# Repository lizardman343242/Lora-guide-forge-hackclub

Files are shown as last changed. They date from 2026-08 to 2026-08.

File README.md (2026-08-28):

# Lora-guide-forge-hackclub





This project follows the stranded guide from forge connecting the RP2040 to the Lora module leading into a antenna 

Bom Table
---
| Id | Designator | Footprint | Quantity | Designation | Supplier and ref |
|----|---|---|---|---|---|
| 1 | AE1 | PinSocket_1x01_P2.54mm_Vertical | 1 | Antenna | |
| 2 | C2, C3 | C_0402_1005Metric | 2 | 100nf | https://jlcpcb.com/partdetail/1877-CL05B104KO5NNNC/C1525|
| 3 | C4 | C_0402_1005Metric | 1 | 470nF | https://jlcpcb.com/partdetail/48344-CL05A474KP5NNNC/C47339|
| 4 | C5, C6 | C_0402_1005Metric | 2 | 47pF | https://jlcpcb.com/partdetail/1919-0402CG470J500NT/C1567|
| 5 | C7 | C_0402_1005Metric | 1 | 1nf | https://jlcpcb.com/partdetail/1875-0402B102K500NT/C1523|
| 6 | C8 | C_0402_1005Metric | 1 | 39pF | https://jlcpcb.com/partdetail/1915-0402CG390J500NT/C1563|
| 7 | C9, C10 | C_0402_1005Metric | 2 | 3.3pf | https://jlcpcb.com/partdetail/1917-0402CG3R3C500NT/C1565|
| 8 | C11, C12, C13, C14, C15, C16, C17, C24, C27, C28 | C_0402_1005Metric | 10 | 100nF | https://jlcpcb.com/partdetail/1877-CL05B104KO5NNNC/C1525|
| 9 | C18, C29 | C_0402_1005Metric | 2 | 1uF | https://jlcpcb.com/partdetail/15107-CL05A105KP5NNNC/C14445|
| 10 | C22, C23 | C_0402_1005Metric | 2 | 15pF | https://jlcpcb.com/partdetail/1900-0402CG150J500NT/C1548|
| 11 | C25, C26 | C_0402_1005Metric | 2 | 10uf | https://jlcpcb.com/partdetail/16204-CL05A106MQ5NUNC/C15525|
| 12 | FB2 | L_0402_1005Metric | 1 | BLM15AX102SN1D | https://jlcpcb.com/partdetail/MurataElectronics-BLM15AX102SN1D/C85815|
| 13 | FL1 | Balun_Johanson_0900FM15K0039 | 1 | 0900FM15K0039 | https://jlcpcb.com/partdetail/JohansonDielectrics-0900FM15K0039E/C5224443|
| 14 | J1 | USB_C_Receptacle_GCT_USB4105-xx-A_16P_TopMnt_Horizontal | 1 | USB_C_Receptacle_USB2.0_16P | https://jlcpcb.com/partdetail/Korean_HropartsElec-TYPE_C_31_M12/C165948|
| 15 | L1 | L_0402_1005Metric | 1 | 15uH | |
| 16 | L2 | L_0402_1005Metric | 1 | 47nH | |
| 17 | L3 | L_0402_1005Metric | 1 | 9.1nH | |
| 18 | R1 | R_0402_1005Metric | 1 | 100 | |
| 19 | R2 | R_0402_1005Metric | 1 | 10k | |
| 20 | R3, R4 | R_0402_1005Metric | 2 | 27.4 | |
| 21 | R5, R6 | R_0402_1005Metric | 2 | 1K | |
| 22 | R7, R8 | R_0402_1005Metric | 2 | 5.1k | |
| 23 | SW1 | SW_Tactile_SPST_NO_Straight_CK_PTS636Sx25SMTRLFS | 1 | BOOT | |
| 24 | SW2 | SW_Tactile_SPST_NO_Straight_CK_PTS636Sx25SMTRLFS | 1 | RESET | |
| 25 | U1 | QFN-24-1EP_4x4mm_P0.5mm_EP2.6x2.6mm | 1 | SX1262IMLTRT | |
| 26 | U2 | QFN-56-1EP_7x7mm_P0.4mm_EP3.2x3.2mm | 1 | RP2040 | |
| 27 | U3 | SOT-363_SC-70-6 | 1 | PE4259 | |
| 28 | U4 | SOIC-8_5.3x5.3mm_P1.27mm | 1 | W25Q128JVS | |
| 29 | U5 | SOT-23-5 | 1 | AP2112K-3.3 | |
| 30 | Y1 | Crystal_SMD_3225-4Pin_3.2x2.5mm | 1 | 32MHz | |
| 31 | Y2 | Crystal_SMD_Abracon_ABM8G-4Pin_3.2x2.5mm | 1 | 12MHz | |
---

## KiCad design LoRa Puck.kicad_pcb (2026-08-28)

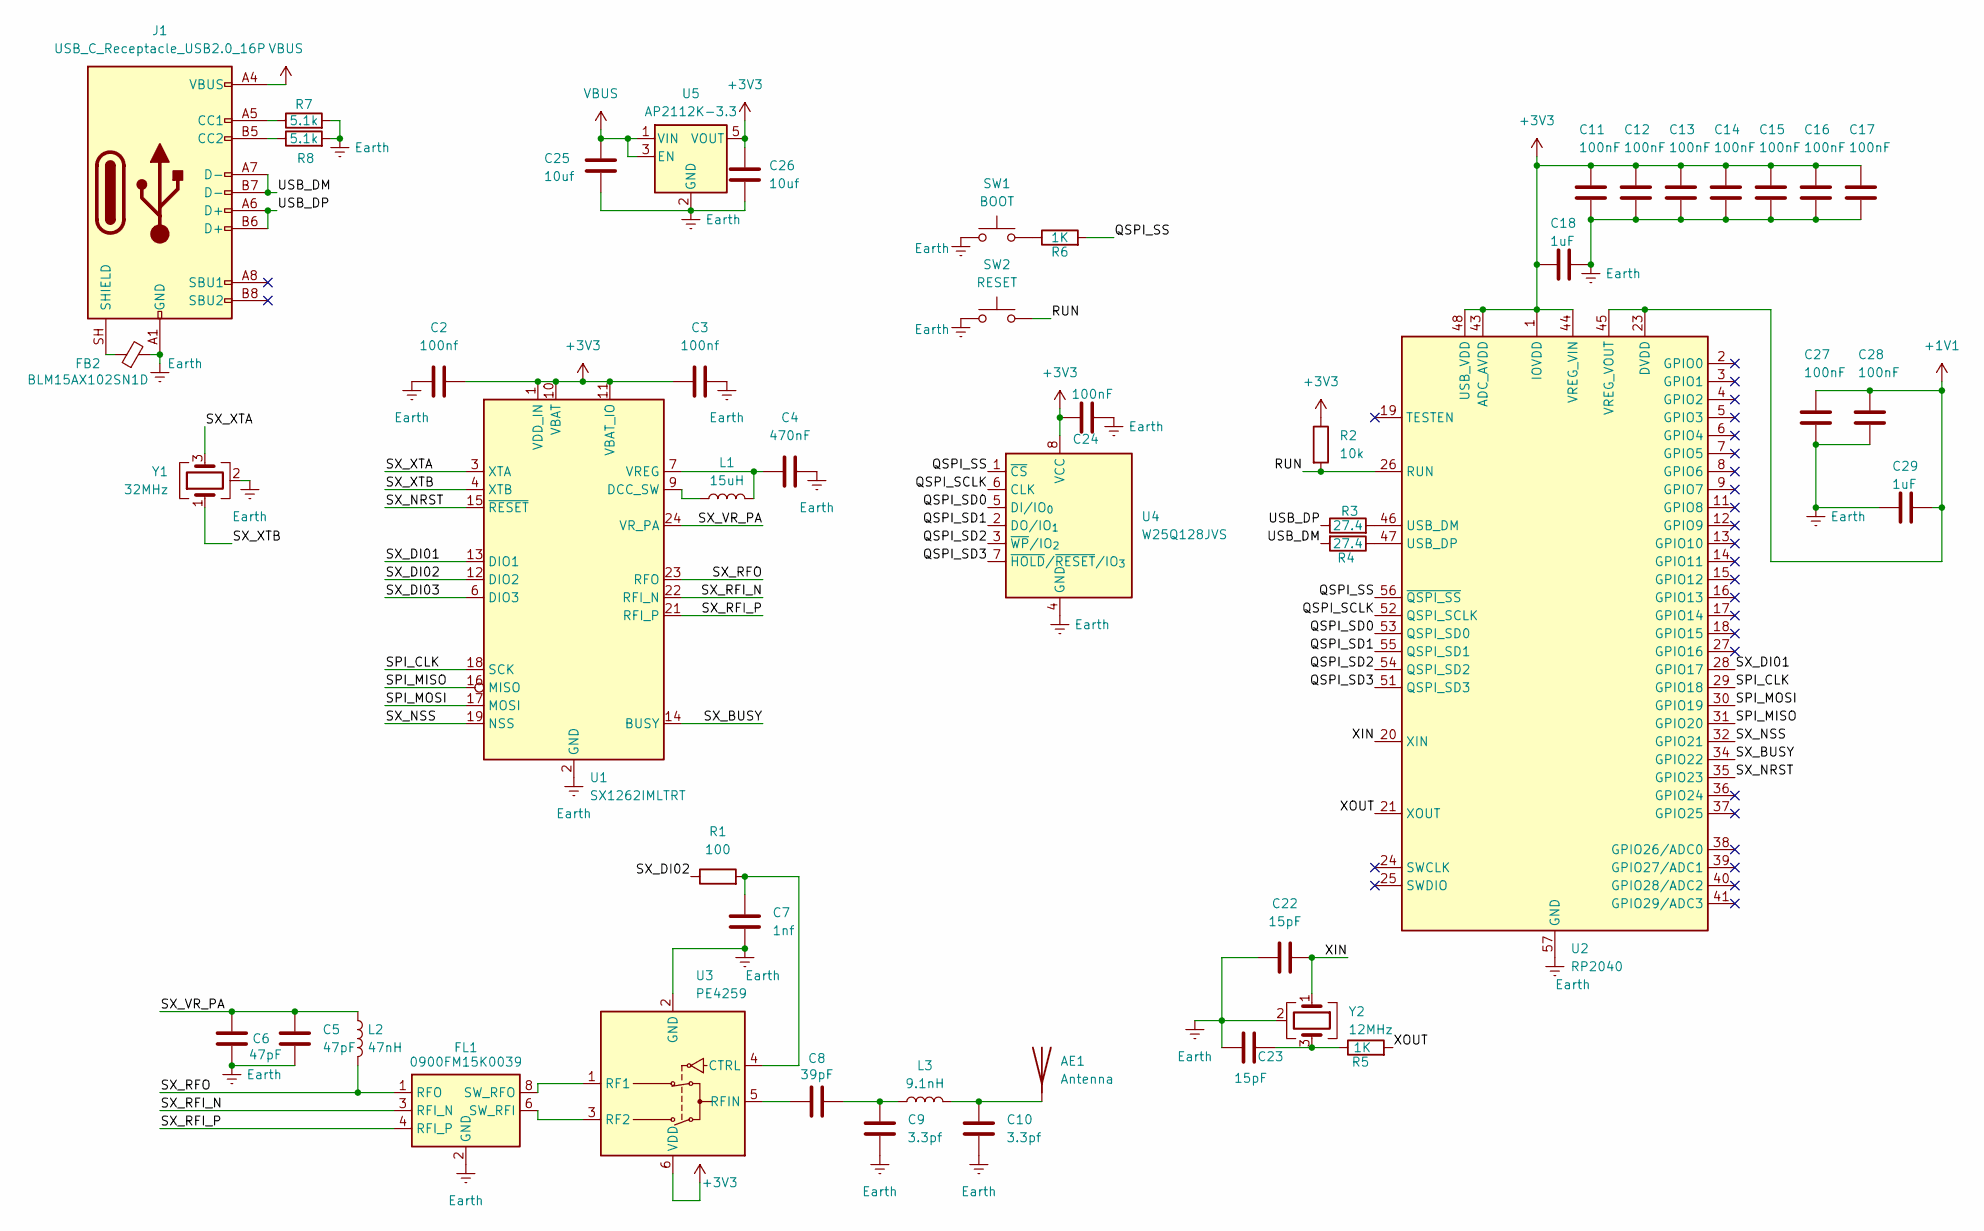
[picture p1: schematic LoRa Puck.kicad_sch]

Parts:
AE1: Antenna; PinSocket_1x01_P2.54mm_Vertical
C2, C3: 100nf; C_0402_1005Metric
C4: 470nF; C_0402_1005Metric
C5, C6: 47pF; C_0402_1005Metric
C7: 1nf; C_0402_1005Metric
C8: 39pF; C_0402_1005Metric
C9, C10: 3.3pf; C_0402_1005Metric
C11, C12, C13, C14, C15, C16, C17, C24, C27, C28: 100nF; C_0402_1005Metric
C18, C29: 1uF; C_0402_1005Metric
C22, C23: 15pF; C_0402_1005Metric
C25, C26: 10uf; C_0402_1005Metric
FB2: BLM15AX102SN1D; L_0402_1005Metric
FL1: 0900FM15K0039; Balun_Johanson_0900FM15K0039
J1: USB_C_Receptacle_USB2.0_16P; USB_C_Receptacle_GCT_USB4105-xx-A_16P_TopMnt_Horizontal
L1: 15uH; L_0402_1005Metric
L2: 47nH; L_0402_1005Metric
L3: 9.1nH; L_0402_1005Metric
R1: 100; R_0402_1005Metric
R2: 10k; R_0402_1005Metric
R3, R4: 27.4; R_0402_1005Metric
R5, R6: 1K; R_0402_1005Metric
R7, R8: 5.1k; R_0402_1005Metric
SW1: BOOT; SW_Tactile_SPST_NO_Straight_CK_PTS636Sx25SMTRLFS
SW2: RESET; SW_Tactile_SPST_NO_Straight_CK_PTS636Sx25SMTRLFS
U1: SX1262IMLTRT; QFN-24-1EP_4x4mm_P0.5mm_EP2.6x2.6mm
U2: RP2040; QFN-56-1EP_7x7mm_P0.4mm_EP3.2x3.2mm
U3: PE4259; SOT-363_SC-70-6
U4: W25Q128JVS; SOIC-8_5.3x5.3mm_P1.27mm
U5: AP2112K-3.3; SOT-23-5
Y1: 32MHz; Crystal_SMD_3225-4Pin_3.2x2.5mm
Y2: 12MHz; Crystal_SMD_Abracon_ABM8G-4Pin_3.2x2.5mm

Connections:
+1V1: C27.2, C28.2, C29.2, U2.23 (DVDD), U2.45 (VREG_VOUT), U2.50 (DVDD)
+3V3: C2.2, C3.1, C11.2, C12.2, C13.2, C14.2, C15.2, C16.2, C17.2, C18.1, C24.2, C26.1, R2.1, U1.1 (VDD_IN), U1.10 (VBAT), U1.11 (VBAT_IO), U2.1 (IOVDD), U2.10 (IOVDD), U2.22 (IOVDD), U2.33 (IOVDD), U2.42 (IOVDD), U2.43 (ADC_AVDD), U2.44 (VREG_VIN), U2.48 (USB_VDD), U2.49 (IOVDD), U3.6 (VDD), U4.8 (VCC), U5.5 (VOUT)
/QSPI_SCLK: U2.52 (QSPI_SCLK), U4.6 (CLK)
/QSPI_SD0: U2.53 (QSPI_SD0), U4.5 (DI/IO_{0})
/QSPI_SD1: U2.55 (QSPI_SD1), U4.2 (DO/IO_{1})
/QSPI_SD2: U2.54 (QSPI_SD2), U4.3 (~WP/IO_{2})
/QSPI_SD3: U2.51 (QSPI_SD3), U4.7 (~HOLD/~RESET/IO_{3})
/QSPI_SS: R6.2, U2.56 (~QSPI_SS), U4.1 (~CS)
/RUN: R2.2, SW2.2, U2.26 (RUN)
/SPI_CLK: U1.18 (SCK), U2.29 (GPIO18)
/SPI_MISO: U1.16 (MISO), U2.31 (GPIO20)
/SPI_MOSI: U1.17 (MOSI), U2.30 (GPIO19)
/SX_BUSY: U1.14 (BUSY), U2.34 (GPIO22)
/SX_DI01: U1.13 (DIO1), U2.28 (GPIO17)
/SX_DI02: R1.1, U1.12 (DIO2)
/SX_DI03: U1.6 (DIO3)
/SX_NRST: U1.15 (~RESET), U2.35 (GPIO23)
/SX_NSS: U1.19 (NSS), U2.32 (GPIO21)
/SX_RFI_N: FL1.3 (RFI_N), U1.22 (RFI_N)
/SX_RFI_P: FL1.4 (RFI_P), U1.21 (RFI_P)
/SX_RFO: FL1.1 (RFO), L2.2, U1.23 (RFO)
/SX_VR_PA: C5.2, C6.2, L2.1, U1.24 (VR_PA)
/SX_XTA: U1.3 (XTA), Y1.3
/SX_XTB: U1.4 (XTB), Y1.1
/USB_DM: J1.A7 (D-), J1.B7 (D-), R4.2
/USB_DP: J1.A6 (D+), J1.B6 (D+), R3.1
/XIN: C22.1, U2.20 (XIN), Y2.1
/XOUT: R5.2, U2.21 (XOUT)
Earth: C2.1, C3.2, C4.2, C5.1, C6.1, C7.2, C9.2, C10.2, C11.1, C12.1, C13.1, C14.1, C15.1, C16.1, C17.1, C18.2, C22.2, C23.2, C24.1, C25.2, C26.2, C27.1, C28.1, C29.1, FB2.2, FL1.2 (GND), FL1.5 (GND), FL1.7 (GND), FL1.9 (GND), FL1.10 (GND), J1.A1 (GND), J1.A12 (GND), J1.B1 (GND), J1.B12 (GND), R7.2, R8.2, SW1.1, SW2.1, U1.2 (GND), U1.5 (GND), U1.8 (GND), U1.20 (GND), U1.25 (GND), U2.57 (GND), U3.2 (GND), U4.4 (GND), U5.2 (GND), Y1.2 (G), Y1.4 (G), Y2.2 (G), Y2.4 (G)
unnamed: AE1.1 (A_1), C10.1, L3.2
unnamed: C8.2, C9.1, L3.1
unnamed: C23.1, R5.1, Y2.3
unnamed: FL1.6 (SW_RFI), U3.3 (RF2)
unnamed: FL1.8 (SW_RFO), U3.1 (RF1)
unnamed: J1.A5 (CC1), R7.1
unnamed: J1.B5 (CC2), R8.1
unnamed: FB2.1, J1.SH (SHIELD)
unnamed: R6.1, SW1.2
unnamed: L1.1, U1.9 (DCC_SW)
unnamed: C4.1, L1.2, U1.7 (VREG)
unnamed: R3.2, U2.46 (USB_DM)
unnamed: R4.1, U2.47 (USB_DP)
unnamed: C7.1, R1.2, U3.4 (CTRL)
unnamed: C8.1, U3.5 (RFIN)
VBUS: C25.1, J1.A4 (VBUS), J1.A9 (VBUS), J1.B4 (VBUS), J1.B9 (VBUS), U5.1 (VIN), U5.3 (EN)

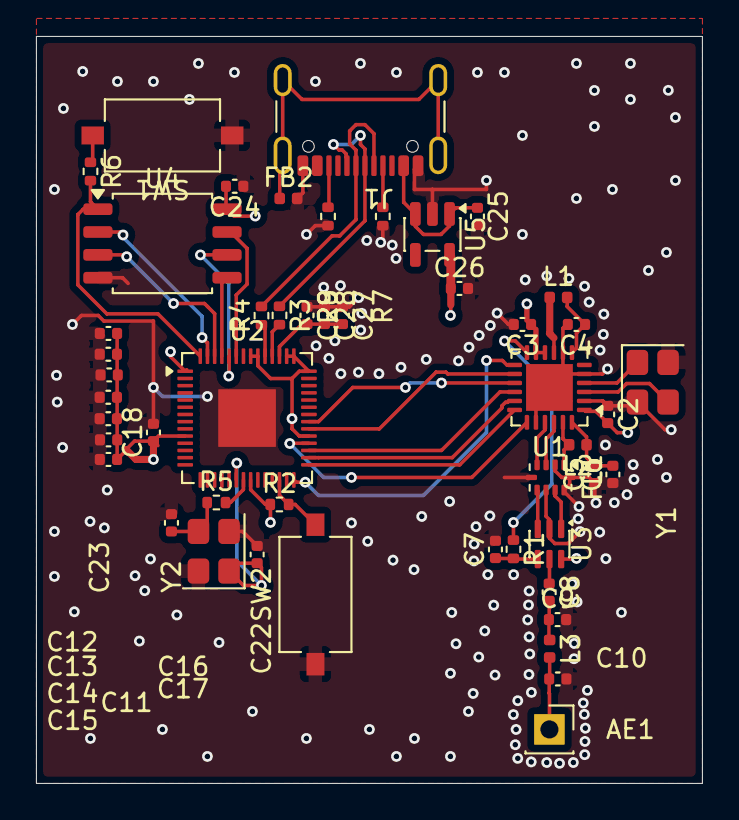
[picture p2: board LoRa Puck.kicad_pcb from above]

Board: 4 copper layers, 37.0 x 41.5 mm, 49 parts (0 on the bottom side), 44 nets.

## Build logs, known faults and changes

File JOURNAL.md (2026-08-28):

---
title: "Lora Puck guide"
author: "jack jenkins"
description: "lora puck pcb guide"
created_at: "2026-03-20"
---

# August 20: Designed the PCB layout

Spent the day laying out traces in KiCad.added in all the components according to the guide including the attenaa and crystals witch are new components witch are new for me. throughout this process many times i had to go back through the guide for all the components i missed


**Total time spent: 1 hours**

# August 21: Placing components

Placed all components in the kicad pcb layout designer. including assigning all the components packages to the symbols and importing them into the layout designer


**Total time spent: 1 hour**

# August 28: routing traces and creating Rf fence

Routed all the tracks, filled the F.Cu ,In1.Cu and B.Cu with Ground planes and turned In2.Cu into a power plane. i spent awhile moving parts around so the vias dont touch with the components like the Raspberry pi and the lora module aswell surrounded the antenna with vias and added my signiture onto it ready for submission to hackclub to approve


images of the finished board

**Total time spent: 2 hour**
